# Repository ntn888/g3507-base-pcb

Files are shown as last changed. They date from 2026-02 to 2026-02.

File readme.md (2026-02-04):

## mspm0g3507 minimal dev board

### Parts list

Red LED 0805- C965812

Blue LED 0805- C965817

Resistor 1K 0805 x2- C95781

Resistor 47K 0805- C126351

Resistor 330 0805- C105877

Resistor 100K 0.1% 0805- C122537

Cap 10nF 0805- C1710

Cap 10uF 0805- C15850

Cap 0.1uF 0805- C49678

Cap 0.47uF 0805- C106843

---

sw_push- C720477

conn01x04 C42431821

conn01x15 C2337

uC- C22362630

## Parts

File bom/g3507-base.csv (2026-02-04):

Id | Designator | Footprint | Quantity | Designation | Supplier and ref
1 | R5 | R_0805_2012Metric_Pad1.20x1.40mm_HandSolder | 1 | 100K 0.1%
2 | C3 | C_0805_2012Metric_Pad1.18x1.45mm_HandSolder | 1 | 0.1uF
3 | C4 | C_0805_2012Metric_Pad1.18x1.45mm_HandSolder | 1 | 0.47uF
4 | C2 | C_0805_2012Metric_Pad1.18x1.45mm_HandSolder | 1 | 10uF
5 | C1 | C_0805_2012Metric_Pad1.18x1.45mm_HandSolder | 1 | 10nF
6 | U1 | LQFP-48_7x7mm_P0.5mm | 1 | mspm0g3507
7 | J1 | PinHeader_1x04_P2.54mm_Horizontal | 1 | Conn_01x04
8 | R1,R4 | R_0805_2012Metric_Pad1.20x1.40mm_HandSolder | 2 | 1K
9 | D2,D1 | LED_0805_2012Metric_Pad1.15x1.40mm_HandSolder | 2 | LED
10 | SW1 | SW_SPST_TS-1088-AR02016 | 1 | SW_Push
11 | R3 | R_0805_2012Metric_Pad1.20x1.40mm_HandSolder | 1 | 330
12 | J3,J2 | PinHeader_1x15_P2.54mm_Vertical | 2 | Conn_01x15
13 | R2 | R_0805_2012Metric_Pad1.20x1.40mm_HandSolder | 1 | 47K

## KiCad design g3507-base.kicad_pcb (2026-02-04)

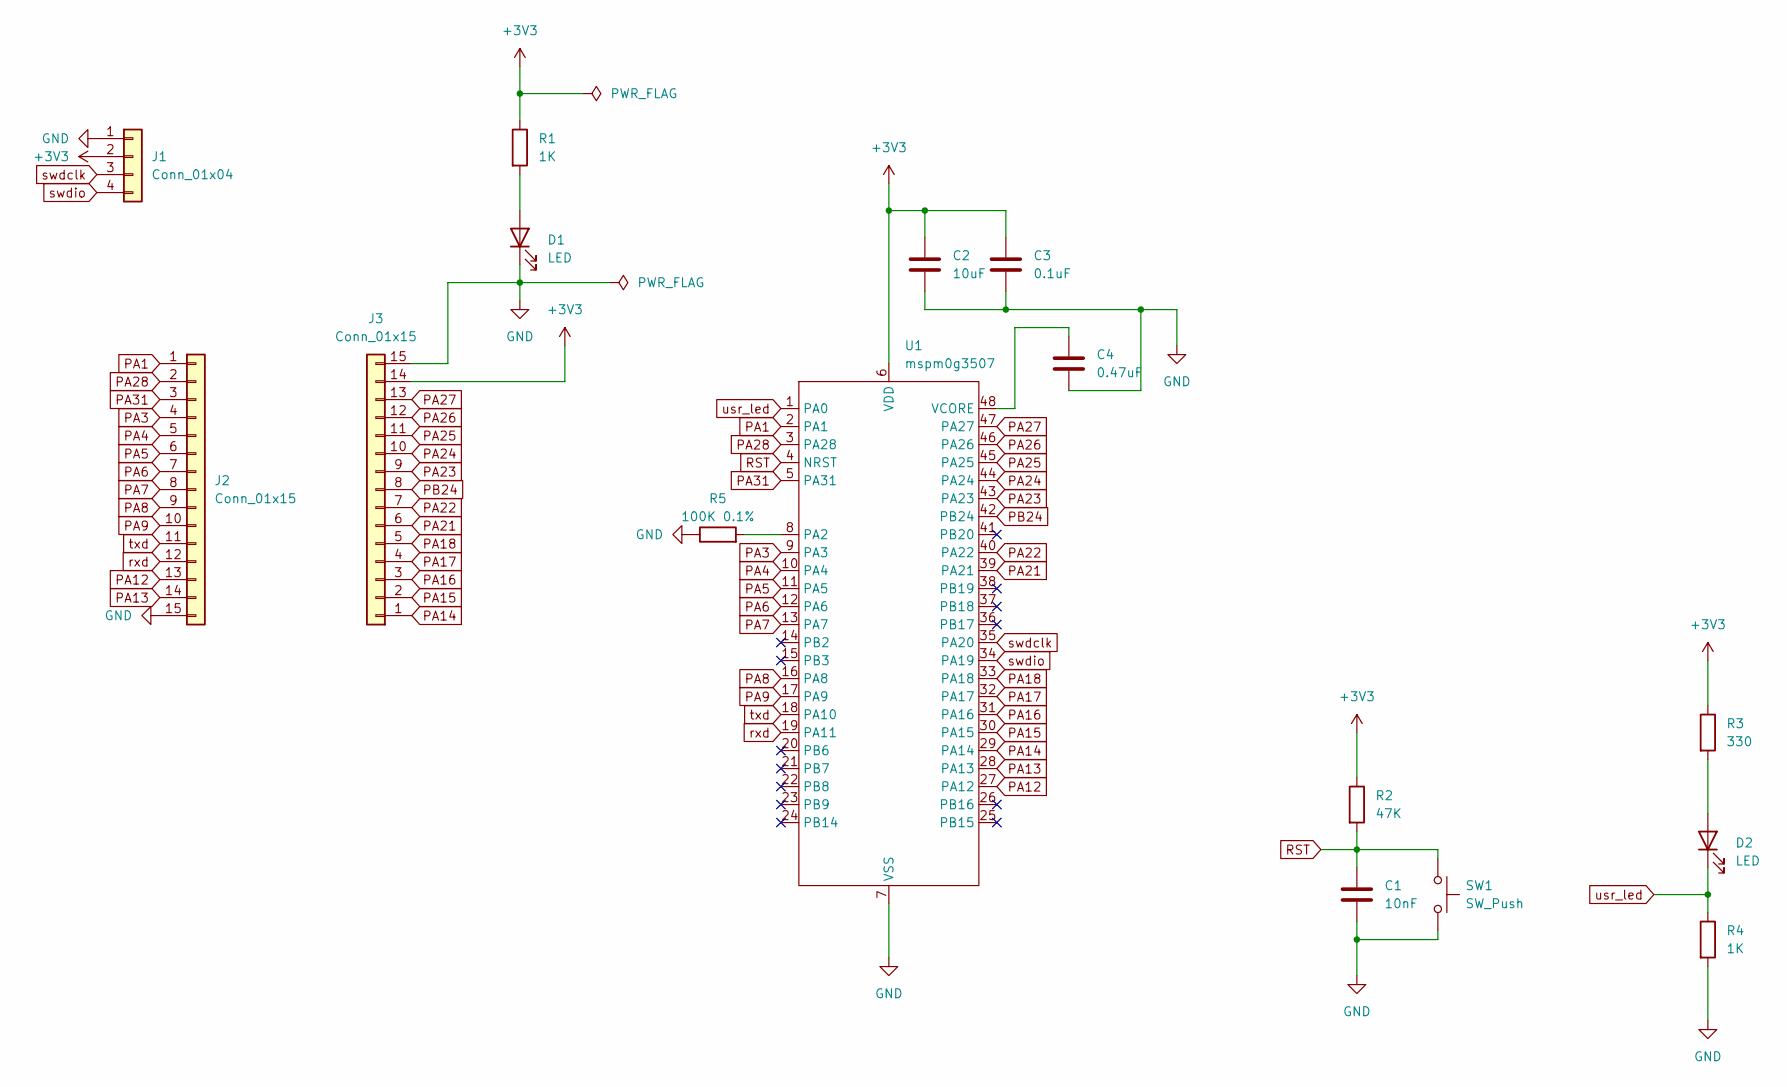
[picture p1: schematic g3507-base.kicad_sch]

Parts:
C1: 10nF; C_0805_2012Metric_Pad1.18x1.45mm_HandSolder
C2: 10uF; C_0805_2012Metric_Pad1.18x1.45mm_HandSolder
C3: 0.1uF; C_0805_2012Metric_Pad1.18x1.45mm_HandSolder
C4: 0.47uF; C_0805_2012Metric_Pad1.18x1.45mm_HandSolder
D1, D2: LED; LED_0805_2012Metric_Pad1.15x1.40mm_HandSolder
J1: Conn_01x04; PinHeader_1x04_P2.54mm_Horizontal
J2, J3: Conn_01x15; PinHeader_1x15_P2.54mm_Vertical
R1, R4: 1K; R_0805_2012Metric_Pad1.20x1.40mm_HandSolder
R2: 47K; R_0805_2012Metric_Pad1.20x1.40mm_HandSolder
R3: 330; R_0805_2012Metric_Pad1.20x1.40mm_HandSolder
R5: 100K 0.1%; R_0805_2012Metric_Pad1.20x1.40mm_HandSolder
SW1: SW_Push; SW_SPST_TS-1088-AR02016
U1: mspm0g3507; LQFP-48_7x7mm_P0.5mm

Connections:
+3V3: C2.1, C3.1, J1.2, J3.14, R1.1, R2.1, R3.1, U1.6 (VDD)
GND: C1.2, C2.2, C3.2, C4.2, D1.1 (K), J1.1, J2.15, J3.15, R4.2, R5.1, SW1.2, U1.7 (VSS)
unnamed: D1.2 (A), R1.2
unnamed: D2.2 (A), R3.2
unnamed: R5.2, U1.8 (PA2)
unnamed: C4.1, U1.48 (VCORE)
PA1: J2.1, U1.2 (PA1)
PA3: J2.4, U1.9 (PA3)
PA4: J2.5, U1.10 (PA4)
PA5: J2.6, U1.11 (PA5)
PA6: J2.7, U1.12 (PA6)
PA7: J2.8, U1.13 (PA7)
PA8: J2.9, U1.16 (PA8)
PA9: J2.10, U1.17 (PA9)
PA12: J2.13, U1.27 (PA12)
PA13: J2.14, U1.28 (PA13)
PA14: J3.1, U1.29 (PA14)
PA15: J3.2, U1.30 (PA15)
PA16: J3.3, U1.31 (PA16)
PA17: J3.4, U1.32 (PA17)
PA18: J3.5, U1.33 (PA18)
PA21: J3.6, U1.39 (PA21)
PA22: J3.7, U1.40 (PA22)
PA23: J3.9, U1.43 (PA23)
PA24: J3.10, U1.44 (PA24)
PA25: J3.11, U1.45 (PA25)
PA26: J3.12, U1.46 (PA26)
PA27: J3.13, U1.47 (PA27)
PA28: J2.2, U1.3 (PA28)
PA31: J2.3, U1.5 (PA31)
PB24: J3.8, U1.42 (PB24)
RST: C1.1, R2.2, SW1.1, U1.4 (NRST)
rxd: J2.12, U1.19 (PA11)
swdclk: J1.3, U1.35 (PA20)
swdio: J1.4, U1.34 (PA19)
txd: J2.11, U1.18 (PA10)
usr_led: D2.1 (K), R4.1, U1.1 (PA0)

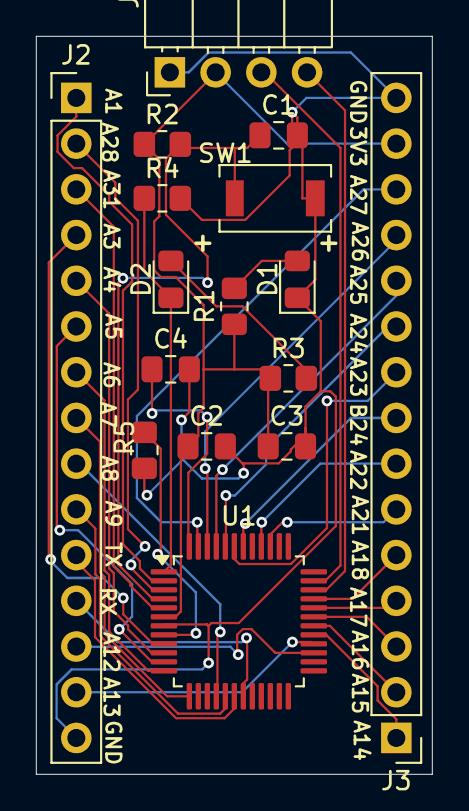
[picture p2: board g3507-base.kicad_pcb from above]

Board: 2 copper layers, 22.0 x 41.0 mm, 16 parts (0 on the bottom side), 37 nets.
